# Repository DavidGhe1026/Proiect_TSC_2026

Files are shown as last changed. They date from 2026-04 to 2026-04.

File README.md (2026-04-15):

# InkTime Hardware Implementation

## Executive summary

This repository documents the **hardware implementation** of the InkTime device as captured in the provided schematic (MCU, power, sensors, haptics, USB, RF, and e‑paper interface circuitry). 

At a high level, the design uses an **nRF52840 SoC** as the main controller, powered from a **single‑cell Li‑ion/LiPo battery** through a **buck‑boost 3.3 V rail**, with **USB‑C input** feeding a **charger/power‑path PMIC**. The MCU communicates with the PMIC, regulator, IMU, fuel gauge, and haptic driver over a shared **I²C bus**, and drives the e‑paper connector using **SPI + GPIO** plus a dedicated **power‑gate and charge‑pump rail generator** for the panel high‑voltage rails. 

A conservative **standby (always‑on) current estimate** for the baseline configuration (MCU in System ON + RTC, regulator enabled, IMU in low‑power mode, fuel gauge in hibernate, haptic driver shut down, PMIC in battery-only mode) is **≈ 26.9 µA**, corresponding to **~155 days (100 mAh)** or **~310 days (200 mAh)** battery life (ignoring cell self‑discharge and assuming the e‑paper power domain is gated off while idle). 

## System block diagram and interconnects

```mermaid
flowchart LR
  USB["USB-C Receptacle"] -->|VBUS| PMIC["BQ25180 Charger + Power-Path"]
  USB -->|D+/D-| ESD["USBLC6-2SC6Y ESD"]
  ESD -->|USB FS| MCU["nRF52840"]

  PMIC -->|VBAT| BAT["1-cell Li-ion/LiPo"]
  BAT -->|VBAT| REG["RT6160A Buck-Boost -> 3V3"]
  REG -->|3V3| MCU

  MCU <-->|I2C| FG["MAX17048 Fuel Gauge"]
  MCU <-->|I2C| IMU["BMA421 Accelerometer"]
  MCU <-->|I2C| HAPT["DRV2605 Haptic Driver"]
  MCU -->|GPIO| BTN["Buttons: Up/Down/Enter"]

  MCU -->|SPI + GPIO| EPDIF["E-paper Connector"]
  MCU -->|PWR_EPD| EPDPOW["EPD Power Gate and Charge Pump"]

```

(Interconnects and blocks derived from the schematic.) 

### Electrical interface summary

The hardware uses four primary interconnect classes:

- **I²C (TWI)**: shared control/telemetry bus for PMIC, buck‑boost regulator, fuel gauge, IMU, and haptic driver.   
- **SPI (SPIM)**: e‑paper interface uses SCK/MOSI/CS plus dedicated GPIOs (DC, RST, BUSY).   
- **USB 2.0 Full Speed (Device)**: D+/D− plus VBUS detect, protected by low-capacitance ESD.   
- **RF single‑ended 2.4 GHz**: SoC ANT pin → matching network → chip antenna.   

Recommended bus configuration choices aligned with the component set:

- **I²C clock**: **400 kHz (Fast-mode)**. The nRF52840 TWI peripheral supports 100 kHz and 400 kHz operation, and DRV2605 explicitly specifies up to 400 kHz SCL without wait states.   
- **SPI mode**: nRF52840 SPIM supports SPI modes **0–3** (CPOL/CPHA configurable). Select the mode required by the e‑paper controller on the attached display/FPC.   
- **SPI frequency**: the nRF52840 supports high‑speed SPI up to **32 MHz** (subject to signal integrity and slave constraints).   

## Bill of materials

The table below lists **major ICs/modules and key electromechanical components**. Any item not clearly available as an in‑catalog JLC assembly part is marked **“JLC Global Sourcing / LCSC”** and should be sourced via that workflow (or substituted with a footprint‑compatible equivalent after verifying electrical limits and package). 

| Item | Designator(s) | MPN / Value | Qty | Purpose | Procurement (JLC preferred) | Datasheet (primary) |
|---|---|---:|---:|---|---|---|
| Main SoC | U1 | nRF52840 (aQFN73/QIAA family) | 1 | MCU + BLE radio + USB FS device | JLC Parts (C190794)  | nRF52840 Product Brief (currents/features); nRF52840 Product Specification (pin mapping, SPIM/TWI/USB details)  |
| Charger + power-path PMIC | IC? (PMIC block) | BQ25180YBGR | 1 | USB-powered Li‑ion charge management + SYS power-path + ship modes | JLC Global Sourcing / LCSC (search by MPN)  | BQ25180 datasheet |
| Buck‑boost 3.3 V regulator | IC? (reg block) | RT6160AWSC | 1 | VBAT → regulated 3V3 rail (I²C configurable) | JLC Global Sourcing / LCSC (search by MPN) | RT6160A datasheet |
| Buck‑boost inductor | L7 | 470 nH (FTC252012SR47MBCA) | 1 | Energy storage for RT6160A | JLC Parts (C5832368) | JLC/LCSC listing (includes datasheet link) |
| Fuel gauge | U3 | MAX17048G+T10 | 1 | Battery SOC/voltage reporting over I²C + alert | JLC Parts (C2682616) | MAX17048/MAX17049 datasheet |
| IMU (accelerometer) | U? (IMU block) | BMA421 | 1 | Motion sensing + interrupts (2x INT) | JLC Global Sourcing / LCSC (search by MPN) | BMA421 datasheet |
| Haptic driver | IC2 | DRV2605YZFR | 1 | Drives ERM/LRA actuator; I²C control | JLC Parts (C133542) | DRV2605 datasheet (I²C timing + currents) |
| USB ESD protection | D3 | USBLC6-2SC6Y (or footprint‑equivalent USBLC6-2SC6) | 1 | Protects D+/D− and VBUS; low line capacitance | JLC Parts (USBLC6‑2SC6, C7519) | USBLC6‑2SC6Y datasheet |
| USB‑C receptacle | J4 | KH‑TYPE‑C‑16P | 1 | USB‑C connection for VBUS and USB data | JLC Parts (C709357) | JLC part listing (datasheet link) |
| E‑paper FPC connector | J1 | 503480‑2400 (24‑pin) | 1 | E‑paper display interconnect | JLC Global Sourcing / LCSC (C2934918 listing) | LCSC listing (mechanical/datasheet link) |
| E‑paper power gate (P‑MOSFET) | Q1 | DMG2305UX‑7 | 1 | Switches EPD_3V3 power domain | JLC Parts (C425246) | JLC listing (datasheet link) |
| E‑paper analog switch / MOSFET | Q3 | SI1308EDL‑T1‑GE3 | 1 | Drives panel high‑voltage switching nodes (GDR/RESE path) | LCSC (C469327) | SI1308EDL datasheet |
| RF antenna | ANT1 | 2450AT18B100E (2.4 GHz chip antenna) | 1 | 2.4 GHz radiator | LCSC (C2917717) | Antenna datasheet (matching/layout guidance) |
| RF matching network | L/C near ANT/FEED | (e.g., 3.3 nH, 0.8 pF per reference values) | 1 set | Match SoC RF to antenna, tune return loss | JLC Parts (value/footprint‑based selection) | nRF52840 reference circuitry section (pin/usage context) |
| Buttons | SW_UP/SW_DN/SW_ENT | Tactile switches + resistors | 3 | User input | JLC Parts (value/footprint‑based selection) | N/A (component-series dependent) |

Notes:
- The schematic explicitly calls out **BQ25180YBGR**, **RT6160AWSC**, **MAX17048G+T10**, **DRV2605YZFR**, **USBLC6-2SC6Y**, **KH-TYPE-C-16P**, **503480-2400**, **DMG2305UX-7**, **SI1308EDL-T1-GE3**, and an **RF chip antenna** in the 2450AT18B100 family.  
- For USB ESD procurement, JLC lists **USBLC6‑2SC6**, while the schematic specifies **USBLC6‑2SC6Y**; they are footprint-compatible variants in the same family. Electrical limits must be checked for your exact variant.   

## Hardware functionality and implementation details

### Power path, charging, and system rails

**USB‑C input and protection.** The USB‑C receptacle provides VBUS and USB data lines; the design includes a dedicated ESD protection device protecting **D+/D− and VBUS** with very low capacitance to preserve signal integrity.  
The selected USBLC6 family is specified for **USB 2.0 ports up to 480 Mb/s** and lists typical **~2.5 pF** line capacitance and very low leakage (nA‑scale), which is appropriate for high‑speed data protection.

**Charger + power-path (BQ25180).** The PMIC provides a USB‑powered single‑cell charger with a regulated system rail (SYS) and multiple ultra‑low power modes. The datasheet indicates a **regulated SYS voltage range of 4.4–4.9 V** (configurable) and **ultra‑low quiescent current modes** including **~3 µA battery-only** and **~3.2 µA ship mode** (typical feature-level statements).  
This PMIC is controlled via **I²C** and can assert an **/INT** line to the MCU for events/faults (as reflected by the schematic net naming and the PMIC datasheet’s host interface concept).

**Battery rail (VBAT).** The battery node is distributed as **VBAT** and is also fed to the fuel gauge and to the buck‑boost converter input. The schematic provides test points for VBAT and ground for characterization.

**3.3 V rail generation (RT6160A buck‑boost).** VBAT is converted to a regulated **3V3** rail by RT6160A, a single‑inductor synchronous buck‑boost with an **I²C interface up to 1 MHz**, programmable VOUT range, and low quiescent current design (single‑digit µA typical, mode-dependent).  
The design uses a dedicated power inductor (470 nH class) consistent with the regulator’s application requirements. 

Operationally:
- At light loads, RT6160A uses automatic PFM/Deep Sleep to maintain efficiency and reduce quiescent loss.   
- The 3V3 rail powers the SoC and all low-voltage peripherals (IMU, fuel gauge, haptic driver logic).   

### Battery fuel gauge telemetry

The design uses **MAX17048** (ModelGauge) to estimate battery state‑of‑charge and voltage via **I²C**, and asserts an **ALRT** interrupt output for configurable thresholds.   
For always‑on operation, MAX17048 supports automatic entry into **hibernate mode (~3 µA)** while maintaining fuel gauging, and **active mode (~23 µA)** when needed.

### IMU (accelerometer) and wake signaling

The IMU is a **BMA421** 3‑axis accelerometer with **I²C/SPI digital interfaces** and **two interrupt pins**, allowing low‑power always‑on event detection without continuous MCU polling.   

Key current modes cited by the datasheet:
- Always-on/low-power operation down to **~13 µA (@ 50 Hz)**.  
- Step-counting “embedded intelligence” example at **~25 µA** (application-context value).  

The schematic routes **INT1** and **INT2** to two independent MCU GPIOs, enabling flexible wake/event mapping (e.g., wake-on-motion vs. tap).

### Haptic driver (DRV2605)

DRV2605 provides ERM/LRA drive with an internal library and closed-loop features, controlled over **I²C**.   
The I²C timing table specifies **fSCL up to 400 kHz** (no wait states), which aligns with using 400 kHz for the shared bus.   

Power management is implemented using the device **EN** pin:
- **Shutdown current** is specified in the **single‑digit µA** range (typ. 1.75 µA).   
This is consistent with an approach where the MCU asserts a dedicated **HAPTIC_EN** GPIO only when haptics are needed. 

### E‑paper connector, power gating, and charge‑pump rails

**Connector and signals.** The e‑paper interface is exposed on a 24‑pin FPC connector and includes:
- SPI signals (SCK, MOSI, CS) and control lines (DC, RST, BUSY).   
- Multiple panel electrode/drive pins labeled `EPD_Cx` (panel‑specific).   

**Dedicated e‑paper power domain (EPD_3V3).** The design includes a **load switch/power gate** using a P‑channel MOSFET (DMG2305UX‑7) controlled by a MCU GPIO (`PWR_EPD`). This enables aggressive power gating of the panel domain when not actively refreshing.   

**Charge pump / high-voltage rails.** The schematic shows a discrete inductor/diode/capacitor network generating labeled rails **PREVGH** and **PREVGL**, typical of e‑paper panel bias generation, using:
- Inductor **L5 = 68 µH**,  
- Multiple **MBR0530** Schottky diodes,  
- High‑voltage capacitors (e.g., 1 µF/50 V class).   
A dedicated MOSFET (SI1308EDL) participates in this drive/rail switching network.   

Because e‑paper panels/controllers vary widely, the exact timing, required rail voltages, and refresh energy depend on the specific display used; the board provides the foundational rails and switching nodes called out in the schematic.   

### USB device, VBUS detect, and ESD strategy

The nRF52840 QIAA package assigns dedicated pads for:
- **VBUS** (USB 5 V input for the on-chip USB regulator),  
- **D−** and **D+**,  
- **DECUSB** (USB 3.3 V regulator decoupling).   

The product specification notes that **VBUS and either VDDH or VDD are required for USB peripheral operation**, and VBUS transitions generate detection events (and can wake from System OFF).   

Externally, the USBLC6 device protects the USB lines while meeting USB 2.0 signal integrity constraints via low capacitance.   

### RF output, matching, and antenna

The nRF52840 provides a dedicated **ANT** RF pin (single-ended antenna connection).   
The schematic includes an RF feed/matching section and a 2.4 GHz chip antenna footprint.   

The selected antenna family (2450AT18B100E) is specified for the 2.4 GHz band (operational frequency range around **2400–2500 MHz** with 50 Ω impedance in the antenna datasheet family), and requires careful PCB layout and matching as guided by the antenna documentation.   

## nRF52840 pin mapping

This section provides an explicit mapping of **board signals → exact nRF52840 pins** and why those pins were selected. Pin naming and ball locations are taken from the nRF52840 QIAA pin assignment table.   
Net names are taken from the schematic. 

### Pin mapping table

| Subsystem | Net / signal | nRF52840 port pin | Package ball / pad | Dir. | Rationale / design notes |
|---|---|---|---|---|---|
| I²C bus | SDA | P0.06 | L1 | I/O | Shared I²C data line to PMIC/regulator/fuel gauge/IMU/haptic; placed on standard GPIO. |
| I²C bus | SCL | P0.07 | M2 | I/O | Shared I²C clock; nRF TWI supports 100/400 kHz; matches DRV2605 max 400 kHz. |
| Fuel gauge | ALERT | P0.09 (NFC1)* | L24 | In | Interrupt from MAX17048 ALRT; uses an available GPIO that is multiplexed with NFC1. |
| PMIC | PMIC_INT | P0.11 | T2 | In | Dedicated PMIC interrupt line; avoids NFC pins; keeps wake sources on port 0. |
| IMU | IMU_INT1 | P0.08 | N1 | In | Primary IMU interrupt line; BMA421 supports 2 interrupts. |
| IMU | IMU_INT2 | P1.08 | P2 | In | Secondary IMU interrupt (e.g., step vs. motion). |
| Haptics | HAPTIC_EN | P0.12 | U1 | Out | Gates DRV2605 EN for lowest-power shutdown when haptics unused. |
| Buttons | SW_UP | P0.13 | AD8 | In | User input GPIO; placed on port 0. |
| Buttons | SW_ENT | P0.14 | AC9 | In | User input GPIO; adjacent to SW_UP for simple routing. |
| Buttons | SW_DN | P1.02 | W24 | In | User input GPIO on port 1; preserves port 0 grouping for display control lines. |
| E‑paper SPI | SCK | P0.02 | A12 | Out | SPI clock; P0.02 is a standard GPIO/analog pin suitable for SPIM mapping. |
| E‑paper SPI | MOSI | P0.03 | B13 | Out | SPI MOSI; display write-only SPI is common; SPIM supports selectable pins. |
| E‑paper SPI | EPD_CS | P0.05 | K2 | Out | Chip select on a nearby GPIO; SPIM can map CSN to any GPIO if needed. |
| E‑paper GPIO | EPD_DC | P0.15 | AD10 | Out | Data/command select; grouped with other display GPIOs (RST/BUSY). |
| E‑paper GPIO | EPD_RST | P0.16 | AC11 | Out | Display reset; grouped with display signals. |
| E‑paper GPIO | EPD_BUSY | P0.17 | AD12 | In | Display busy/status; grouped with display signals. |
| E‑paper power | PWR_EPD | P1.01 | Y23 | Out | Enables the EPD_3V3 load switch to fully gate the high-draw e‑paper domain while idle. |
| USB | D− | D− | AD4 | I/O | Dedicated USB D− pin (USBD). |
| USB | D+ | D+ | AD6 | I/O | Dedicated USB D+ pin (USBD). |
| USB | VBUS detect / LDO input | VBUS | AD2 | In (power sense) | Required for USBD operation and VBUS detection events. |
| Debug | SWDIO | SWDIO | AC24 | I/O | SWD programming/debug. |
| Debug | SWDCLK | SWDCLK | AA24 | In | SWD clock. |
| Reset | nRESET | P0.18 / nRESET | AC13 | In | External reset capability configured on P0.18. |
| RF | ANT | ANT | H23 | RF | Single-ended antenna port → matching → antenna. |
| HF crystal | XC1 / XC2 | XC1 / XC2 | B24 / A23 | Analog | External 32 MHz crystal pins for the high-frequency clock reference. |
| LF crystal | XL1 / XL2 | P0.00 / P0.01 | D2 / F2 | Analog | 32.768 kHz crystal pins (low-frequency clock). |

\* **Note on NFC pins used as GPIO:** P0.09 and P0.10 are multiplexed with NFC1/NFC2 (NFCT antenna pins). Using P0.09 as a GPIO for ALERT implies the NFC function is not used (NFCT antenna would otherwise connect between NFC1 and NFC2).

## Power budget and battery-life estimates

This section provides a **standby baseline** and an example **active contributor** model. All currents below are **typical datasheet values** at nominal supply and assume the design is configured to use each component’s low‑power mode.

### Standby baseline current model

Assumed baseline state:
- nRF52840 in **System ON, full RAM retention + RTC** (wake on GPIO/RTC/interrupt).   
- RT6160A regulator enabled at light load (low quiescent current regime).   
- BQ25180 in **battery-only mode** (no adapter present).   
- MAX17048 in **hibernate**.  
- BMA421 in **low-power mode (~13 µA @ 50 Hz)**.  
- DRV2605 held in **shutdown via EN**.  
- E‑paper power domain gated off (PWR_EPD low).  

| Block | Typical current used | Source |
|---|---:|---|
| nRF52840 (System ON + RTC + full RAM retention) | 3.16 µA | nRF52840 product brief |
| RT6160A buck‑boost (light‑load quiescent) | 3 µA (typical feature statement) | RT6160A datasheet |
| BQ25180 (battery‑only mode) | 3 µA | BQ25180 datasheet |
| MAX17048 (hibernate) | 3 µA | MAX17048 datasheet |
| BMA421 (low‑power mode @ 50 Hz) | 13 µA | BMA421 datasheet |
| DRV2605 (shutdown) | 1.75 µA (typical) | DRV2605 datasheet |
| **Total baseline** | **≈ 26.9 µA** | Sum of the above |

### Standby current visualization (Mermaid bar chart)

```mermaid
xychart-beta
  title "Standby Current Contributors (Typical, µA)"
  x-axis ["nRF52840","RT6160A","BQ25180","MAX17048","BMA421","DRV2605"]
  y-axis "µA" 0 --> 30
  bar [3.16,3.0,3.0,3.0,13.0,1.75]
```

(Values used are taken from the cited datasheets/product brief above.) 

### Battery life examples (100 mAh and 200 mAh)

Battery life estimate uses:

<!-- \[
\text{Life (hours)} \approx \frac{C_{\text{mAh}}}{I_{\text{avg(mA)}}}
\quad\text{with}\quad
I_{\text{avg(mA)}} = \frac{I_{\text{avg(µA)}}}{1000}
\] -->

Baseline standby average current: **26.9 µA** (0.0269 mA). (Derived from the table above.) 

| Cell capacity | Avg current | Estimated life (hours) | Estimated life (days) |
|---:|---:|---:|---:|
| 100 mAh | 26.9 µA | ~3716 h | **~155 days** |
| 200 mAh | 26.9 µA | ~7432 h | **~310 days** |

These values **exclude**:
- cell self‑discharge,
- regulator efficiency variation with temperature/load,
- any periodic BLE, display refresh, or haptic events,
- leakage through external connectors/cabling.   

### Example “active contributor” model: BLE advertising overhead

The nRF52840 radio current is listed as **6.40 mA at 0 dBm TX** (DC/DC @ 3 V) and **6.26 mA in RX (1 Mbps)**.  

<!-- If the device performs periodic advertisements, the average current contribution is dominated by **TX/RX duty cycle**. A simple approximation:

\[
I_{\text{adv,avg}} \approx I_{\text{TX}} \cdot \frac{t_{\text{radio}}}{T_{\text{interval}}}
\] -->

<!-- **Worked example (assumption):** advertising interval **1 s**, total radio-on time **3 ms per interval** (3 channels + overhead).  
Then \( I_{\text{adv,avg}} \approx 6.4\text{ mA} \cdot 0.003 = 19.2\text{ µA} \). (TX current from datasheet; timing is a workload assumption.)   -->

New average: \( 26.9 + 19.2 \approx 46.1 \) µA.

| Cell capacity | Avg current | Estimated life (days) |
|---:|---:|---:|
| 100 mAh | ~46.1 µA | ~90 days |
| 200 mAh | ~46.1 µA | ~181 days |

## Assumptions and ambiguity list

1. **Exact nRF52840 orderable variant/package.** The schematic labels the SoC generically while the pinout corresponds to the **QIAA/aQFN73** variant (USB dedicated pins, SWD ball names). The BOM assumes the commonly stocked QIAA family part used by JLC (C190794) and uses the QIAA pin assignment table for ball names.   
2. **E‑paper panel/controller specifics are not provided.** The connector and discrete rail generation (PREVGH/PREVGL, GDR/RESE) are present, but **SPI mode, refresh timing, and refresh energy** depend on the attached panel/controller. The README treats these as panel‑dependent.   
3. **Procurement availability on JLC can change.** For components not explicitly found as a JLC in-catalog part in this research pass (e.g., BQ25180YBGR, RT6160AWSC, BMA421), procurement is marked **JLC Global Sourcing / LCSC search by MPN**, and an exact order flow should be validated before finalizing the assembly BOM.   
4. **USB ESD part number variant.** The schematic specifies USBLC6‑2SC6Y; JLC’s catalog listing used here is USBLC6‑2SC6 (same package family). Confirm the exact suffix requirements (automotive grade, qualification) for your build.   
5. **Power budget uses typical values and specific low-power modes.** Real current depends on firmware configuration (sleep state, RTC usage, GPIO pulls), regulator mode, and sensor configuration. The table is intended as an engineering starting point; measurement on the assembled board is required for sign-off.

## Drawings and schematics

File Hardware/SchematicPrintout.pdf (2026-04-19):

E-paper Drive Circuit | TP_OP

# TP_ON Haptic Driver

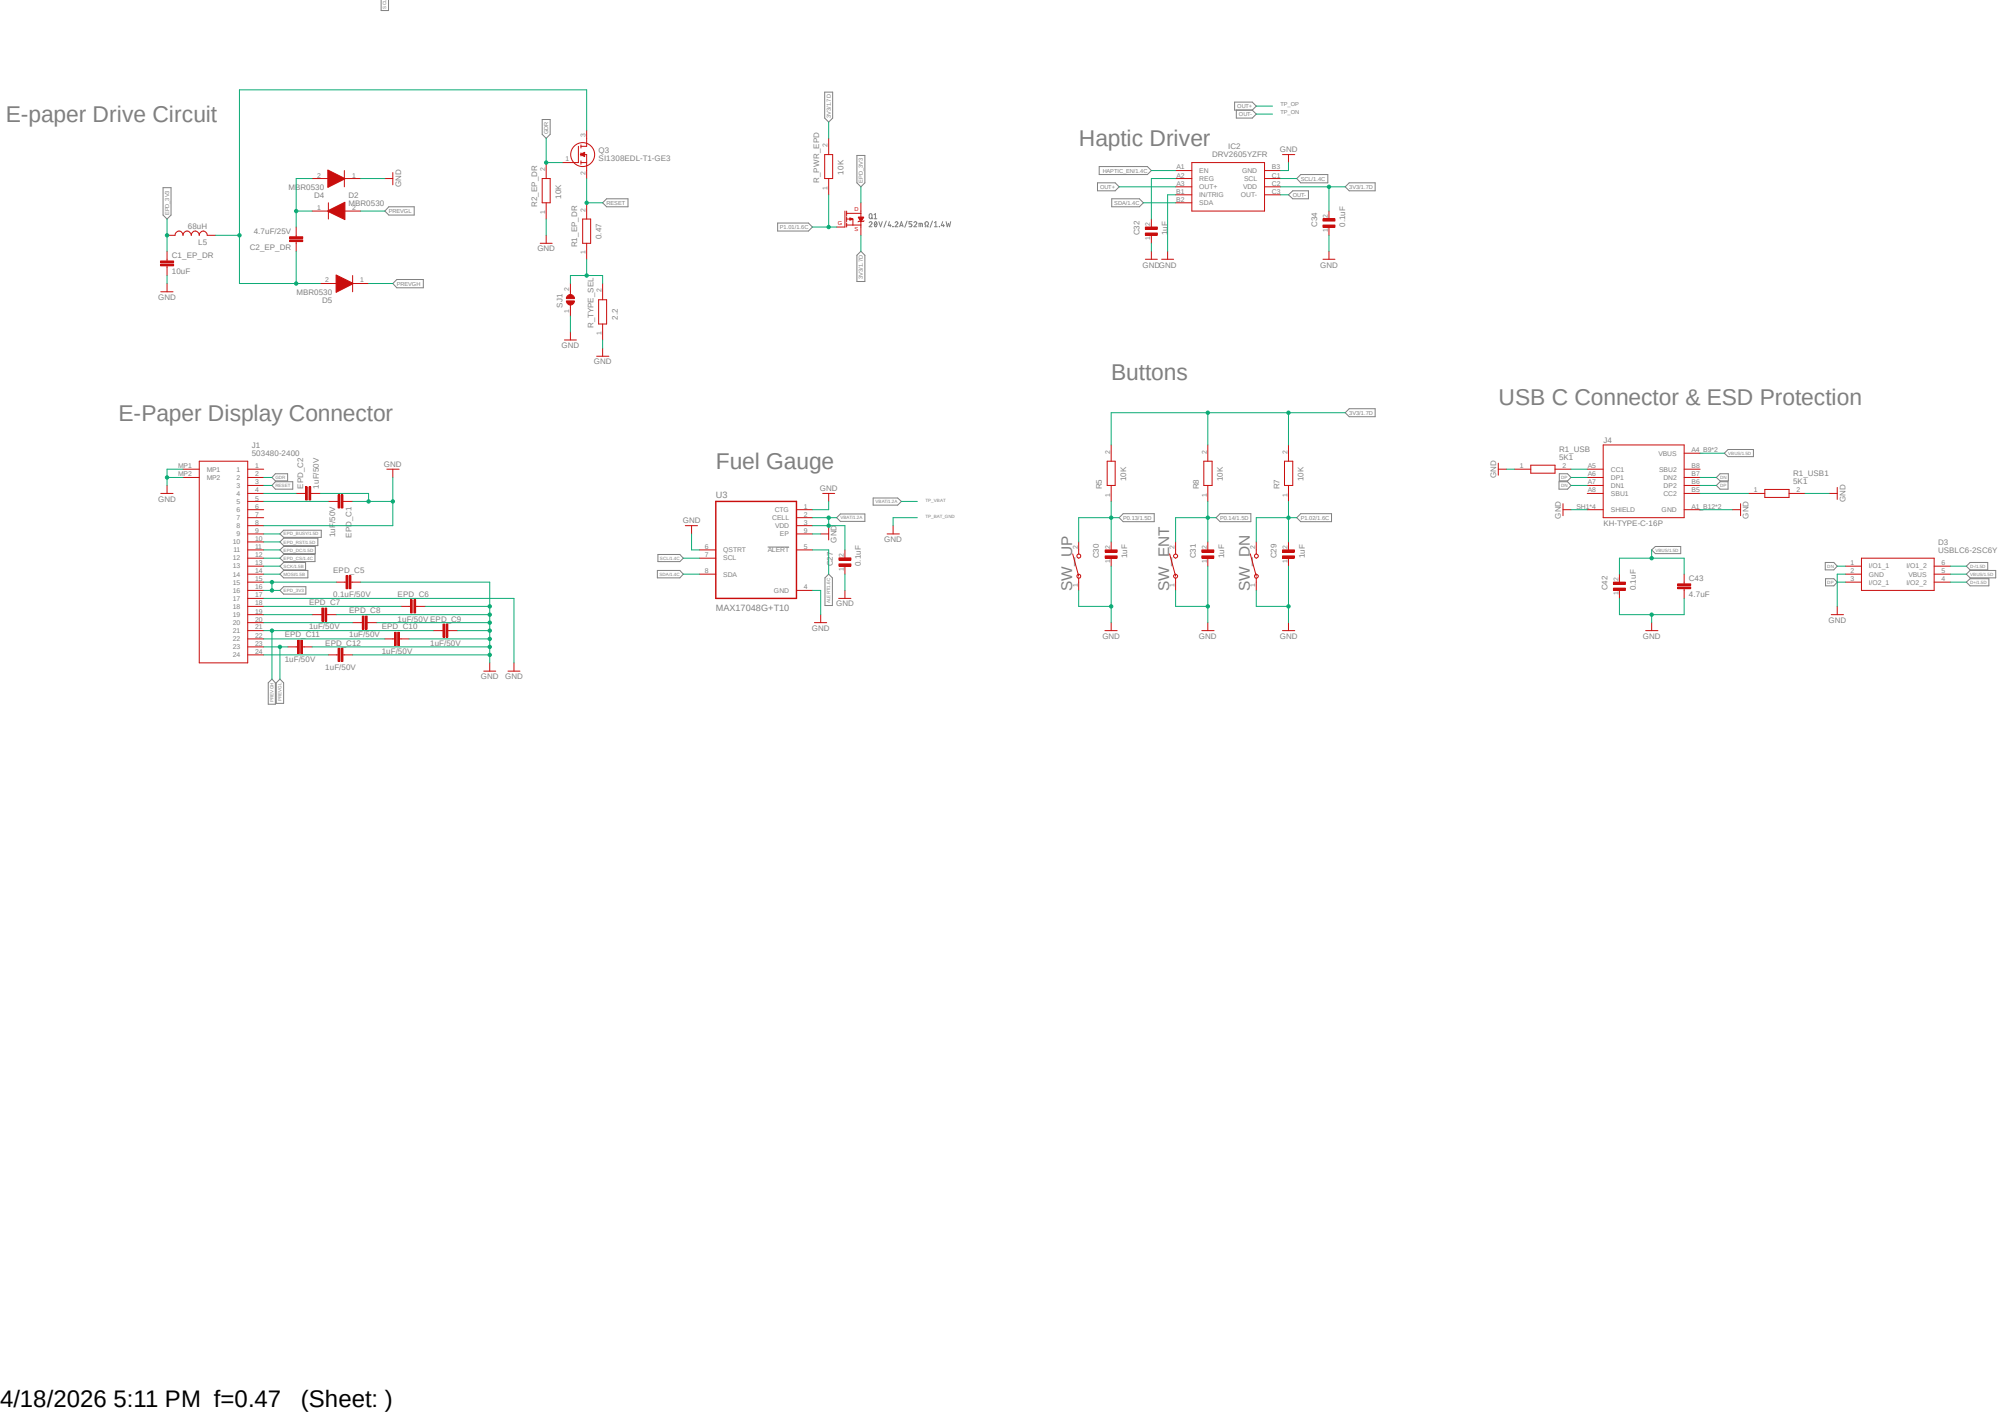
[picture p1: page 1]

USB C Connector & ESD Protection

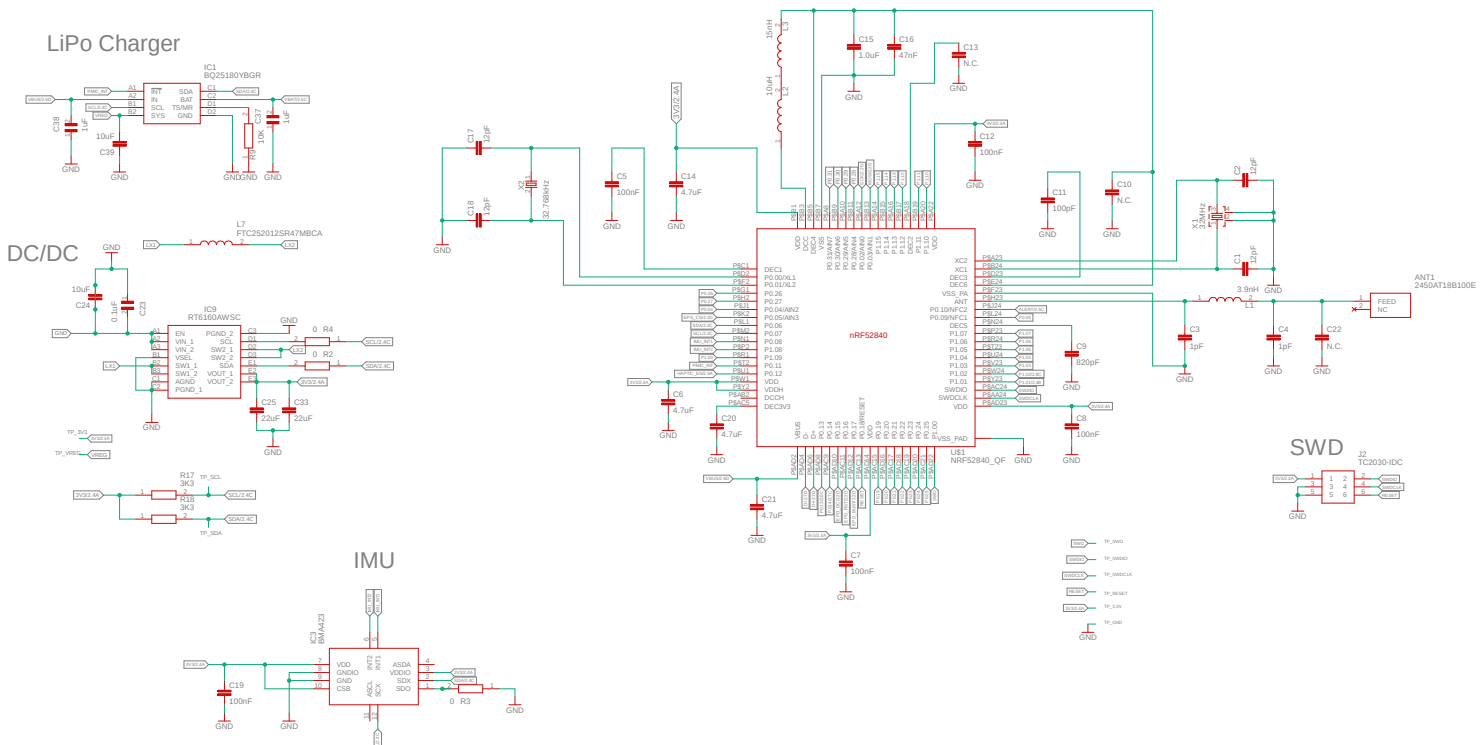
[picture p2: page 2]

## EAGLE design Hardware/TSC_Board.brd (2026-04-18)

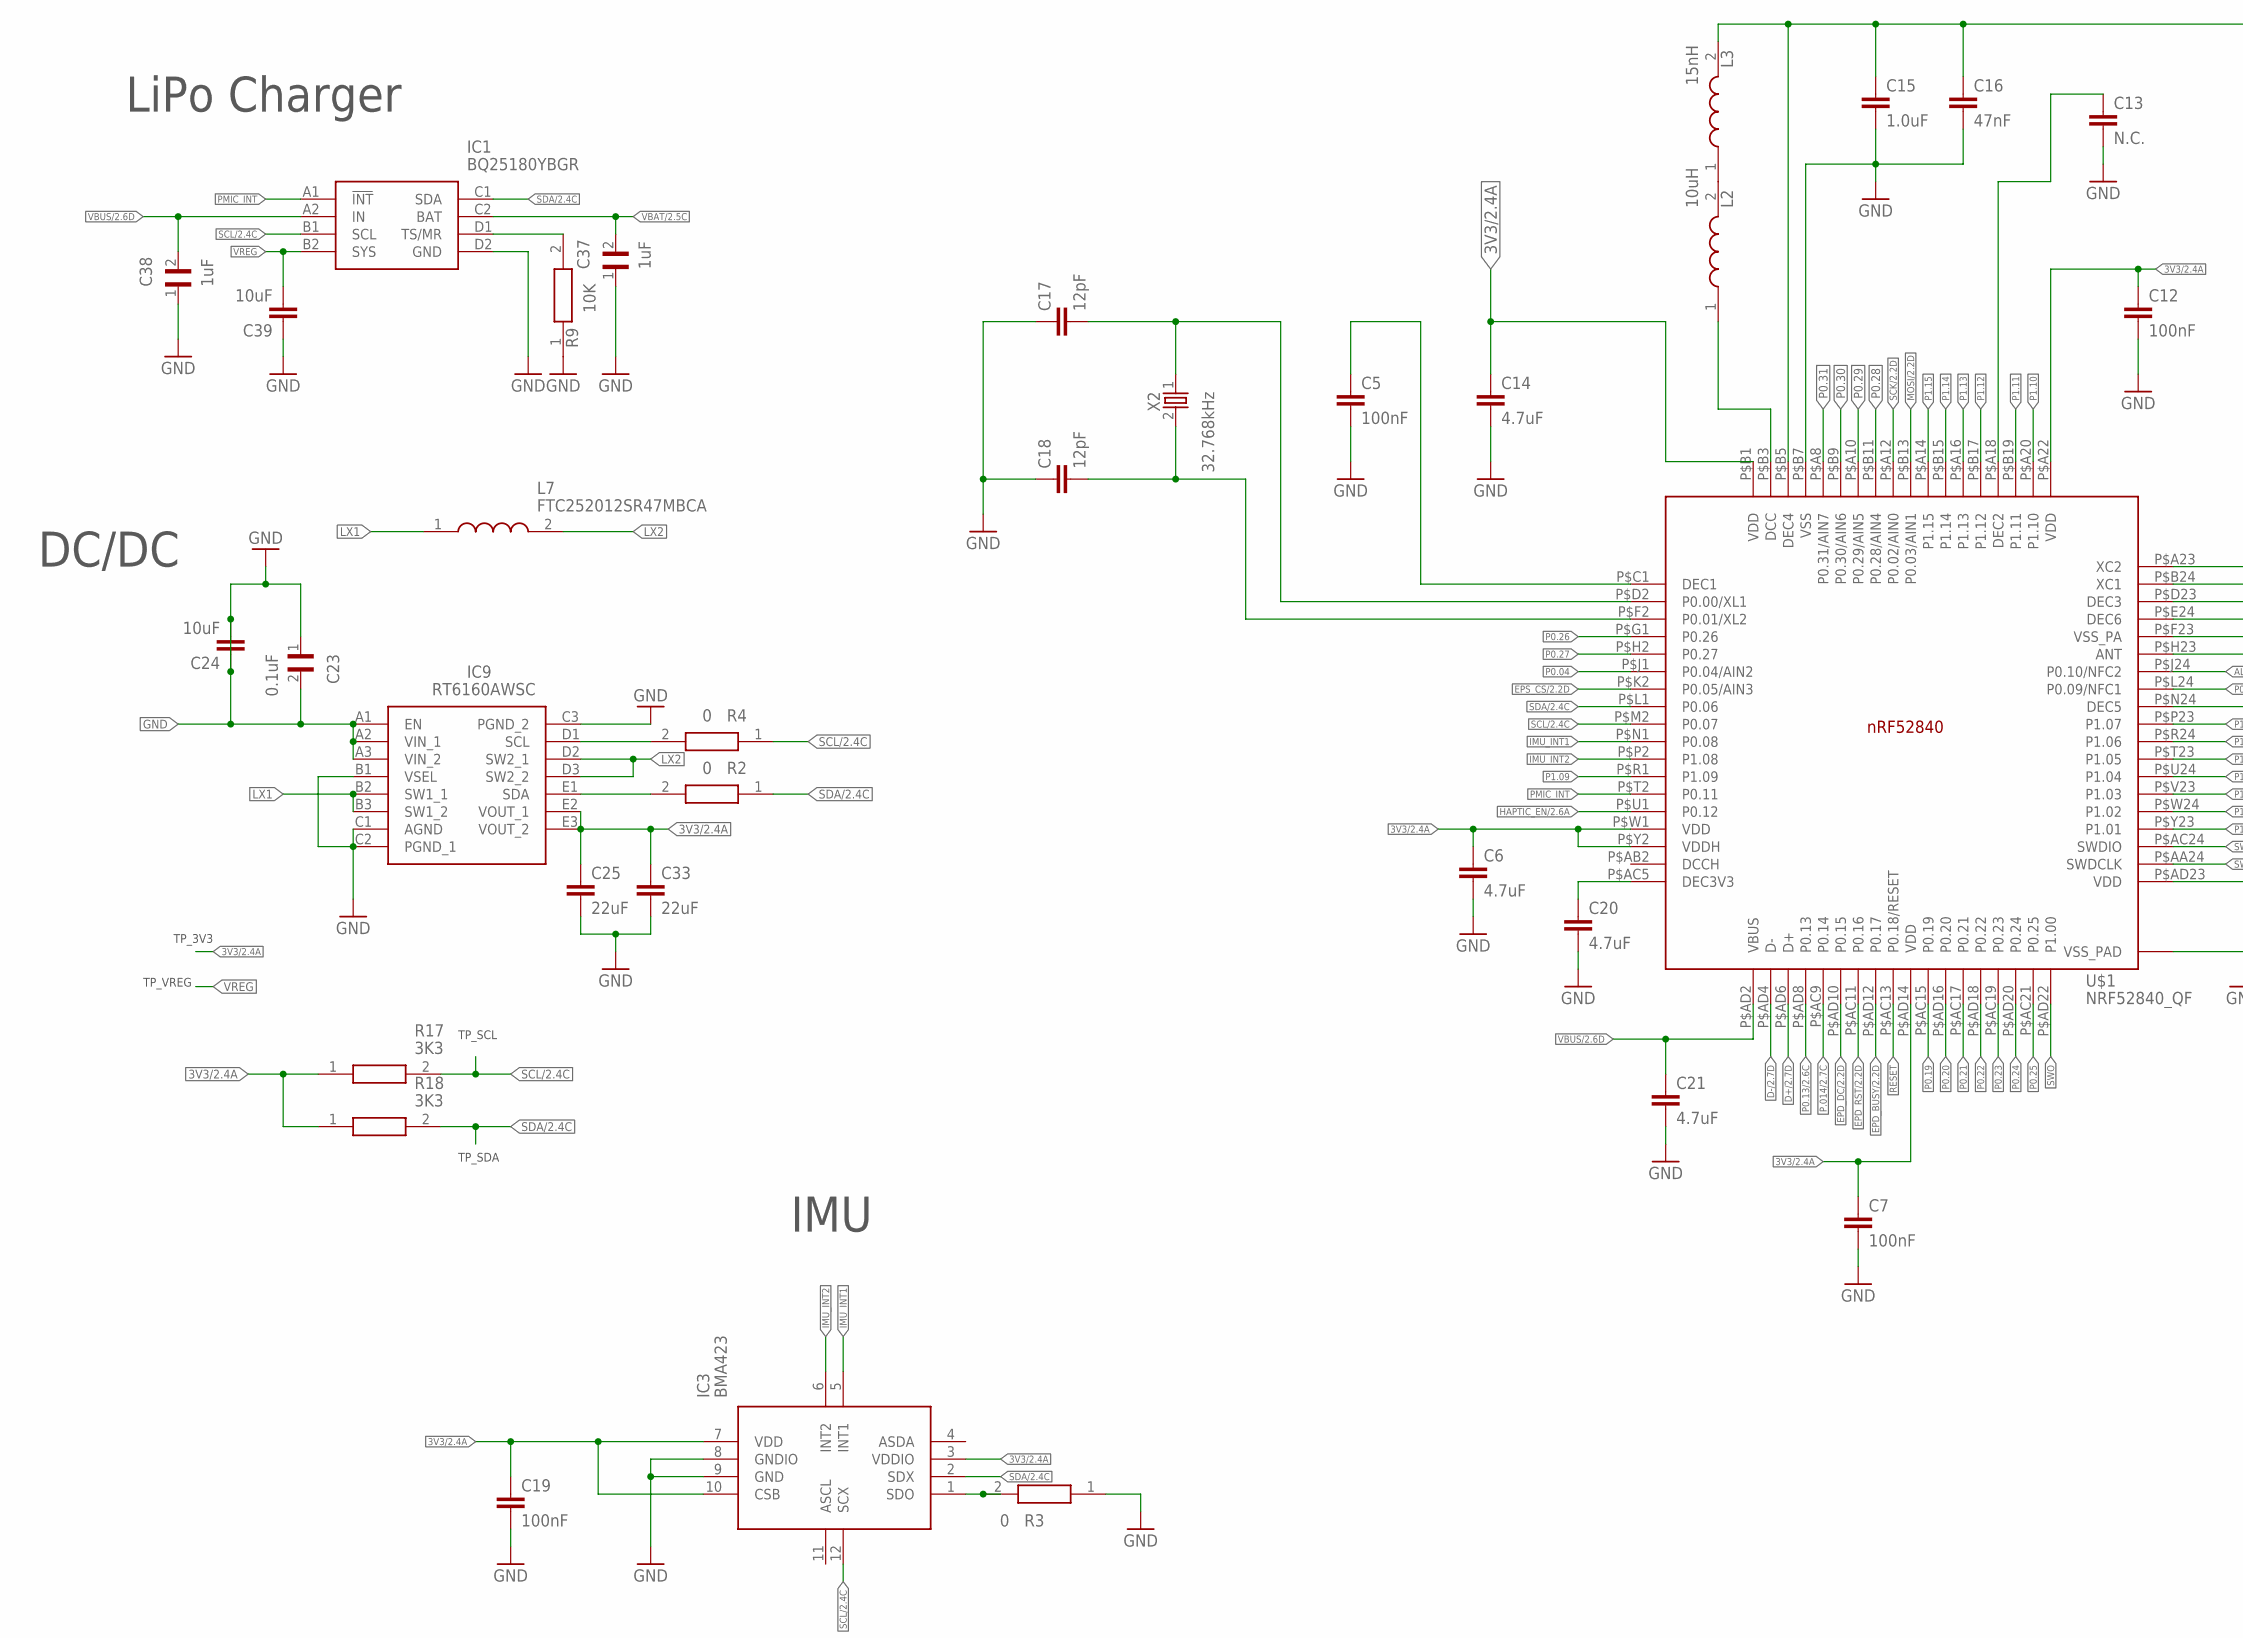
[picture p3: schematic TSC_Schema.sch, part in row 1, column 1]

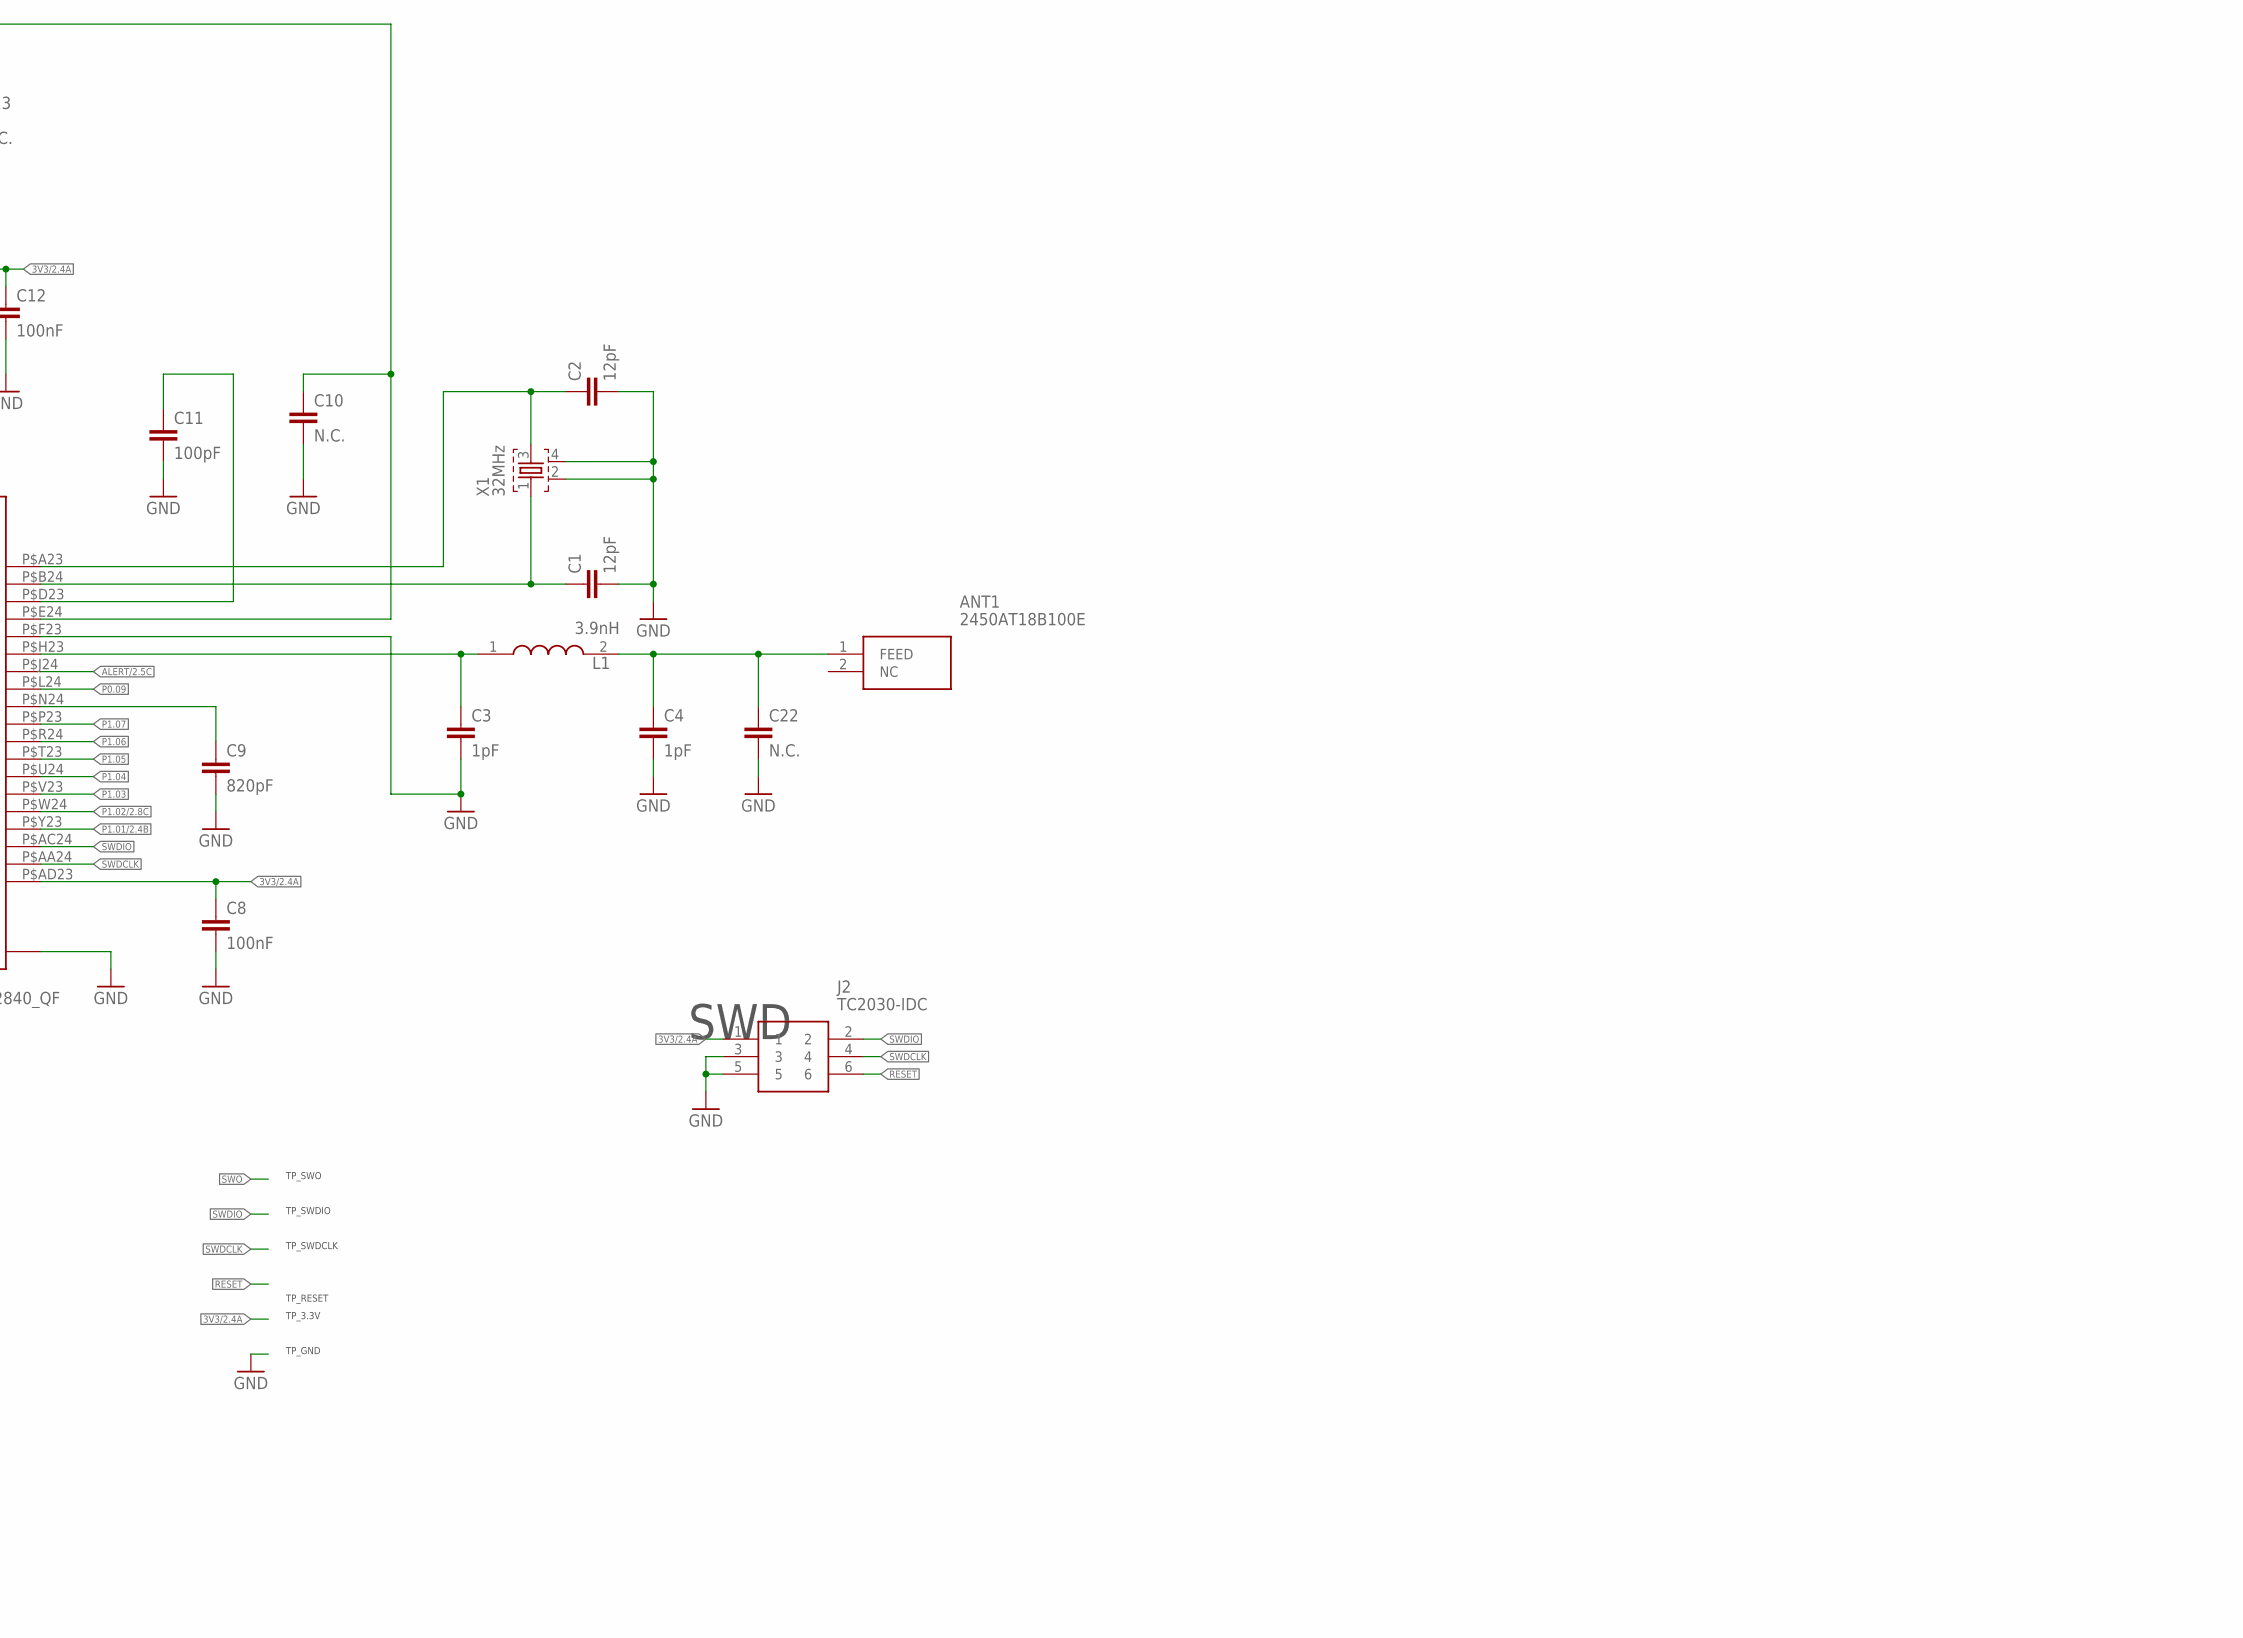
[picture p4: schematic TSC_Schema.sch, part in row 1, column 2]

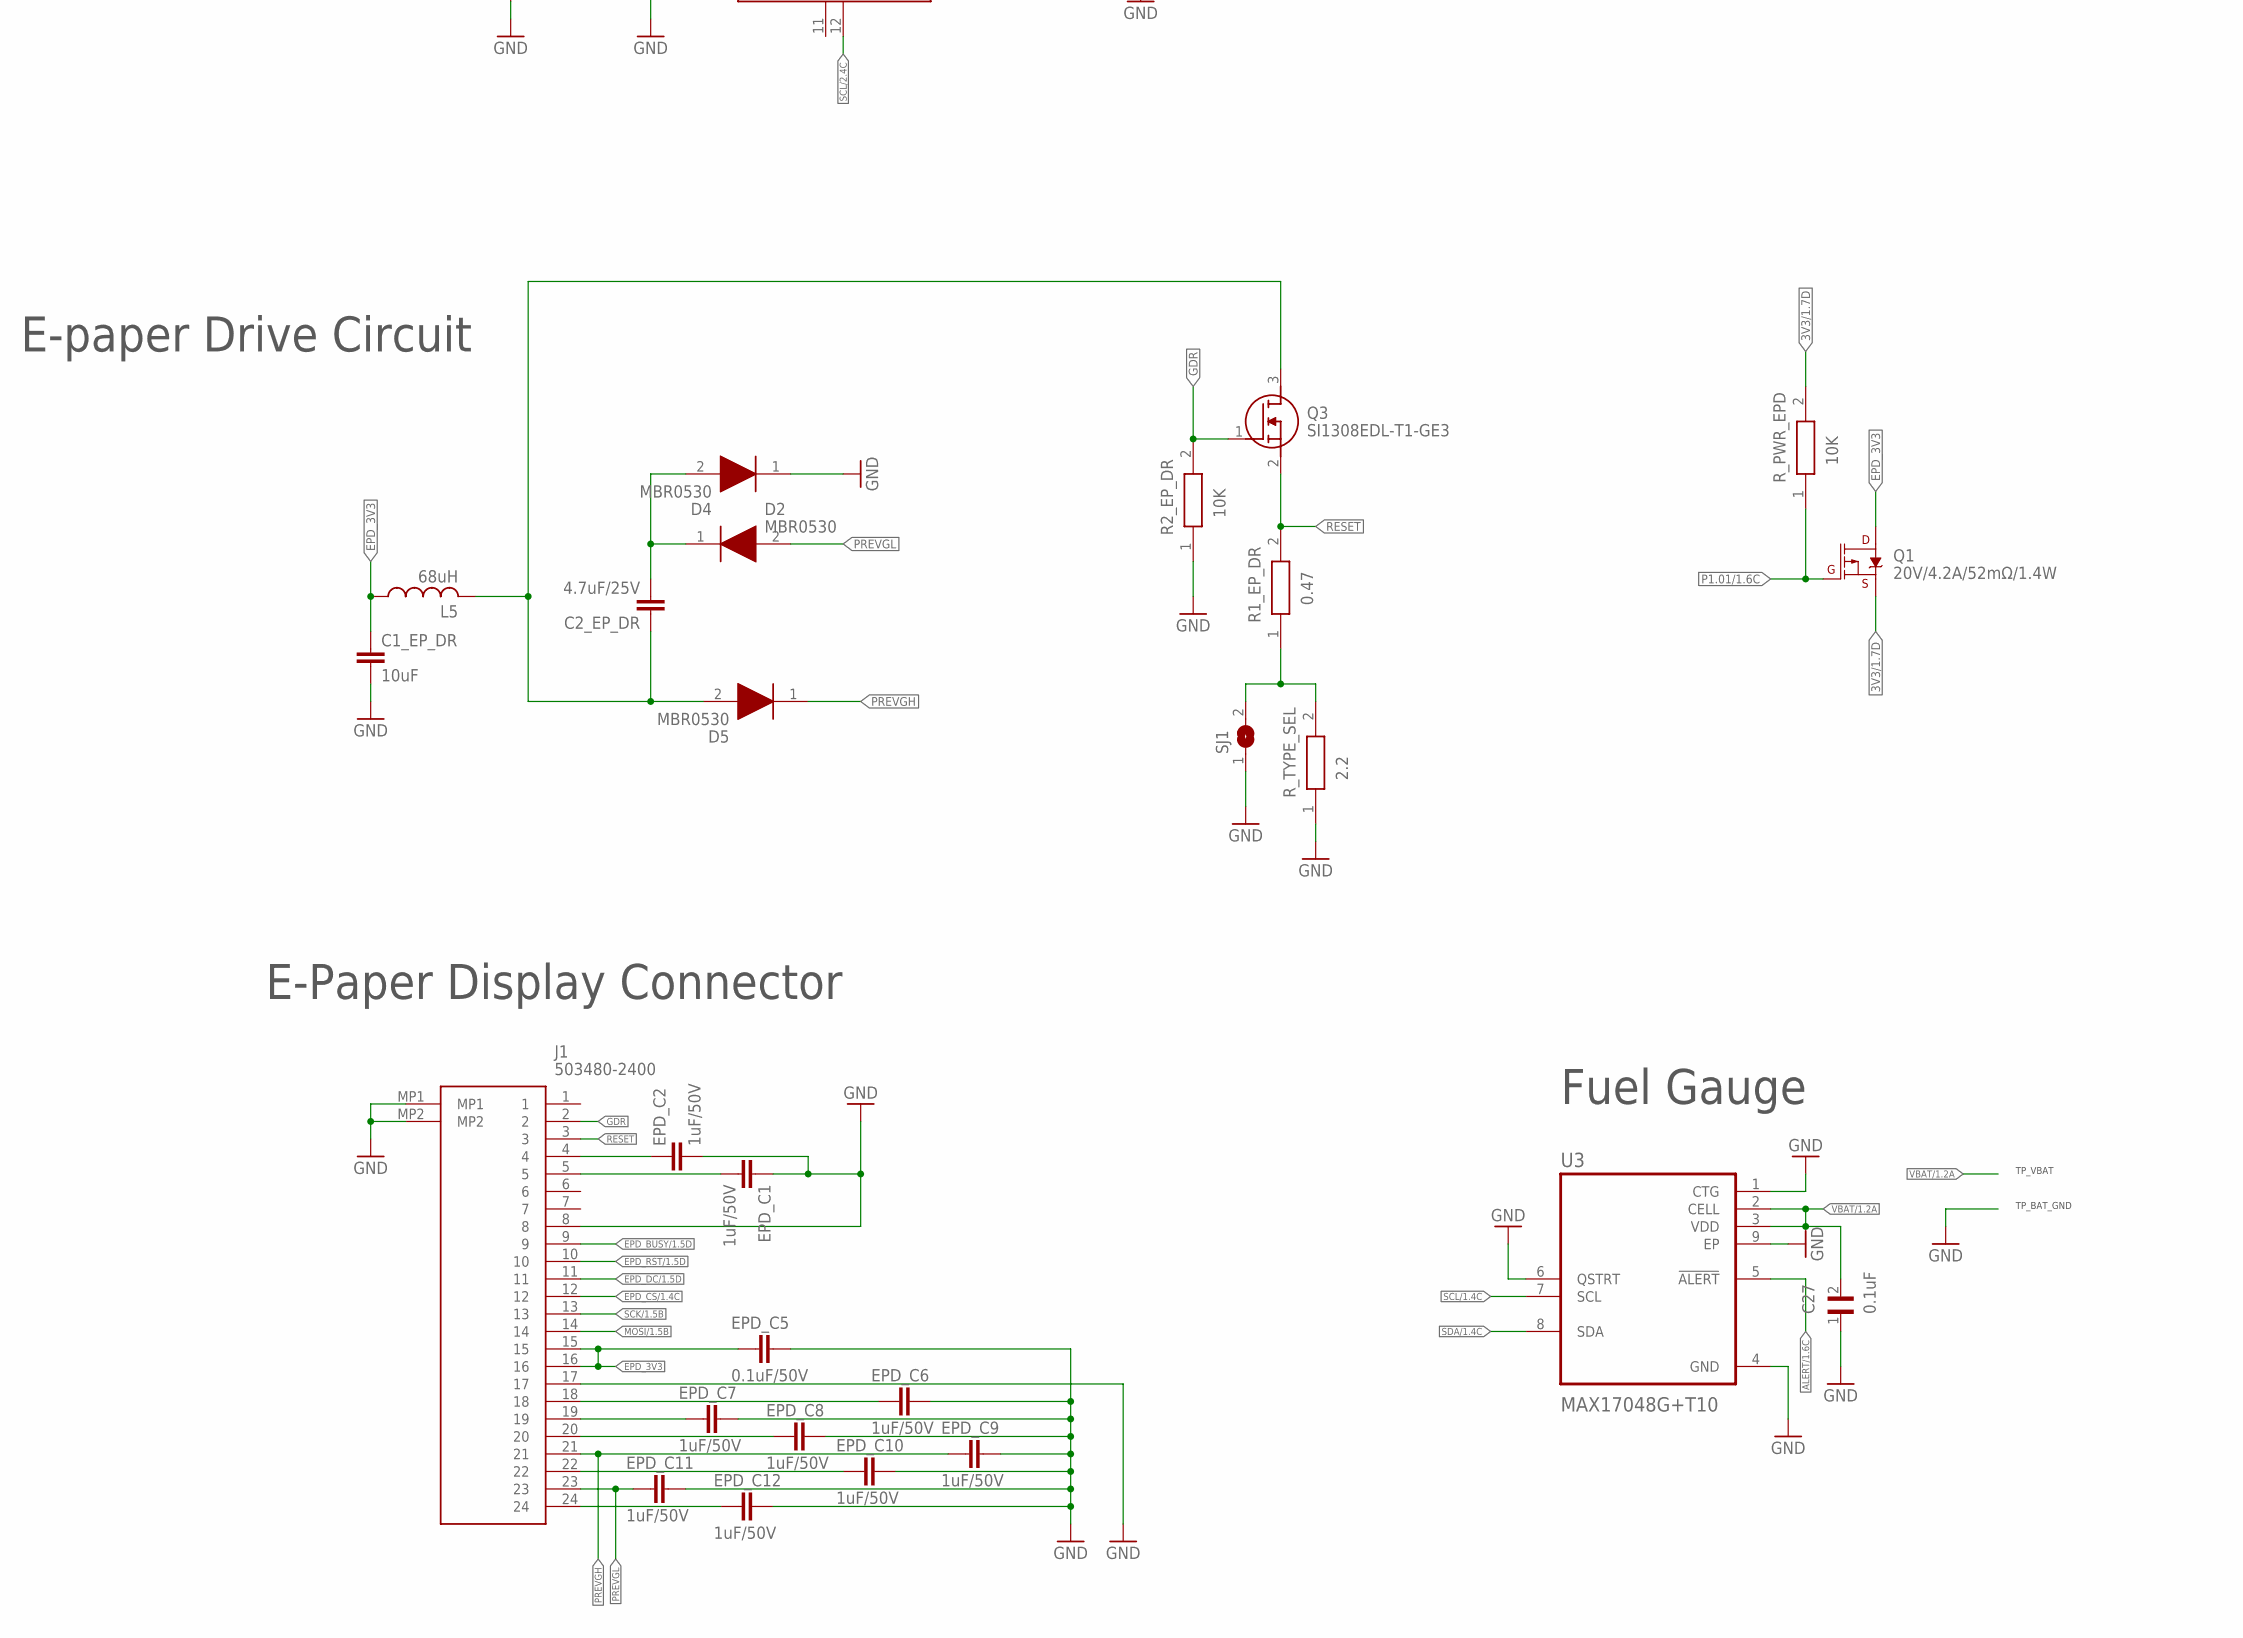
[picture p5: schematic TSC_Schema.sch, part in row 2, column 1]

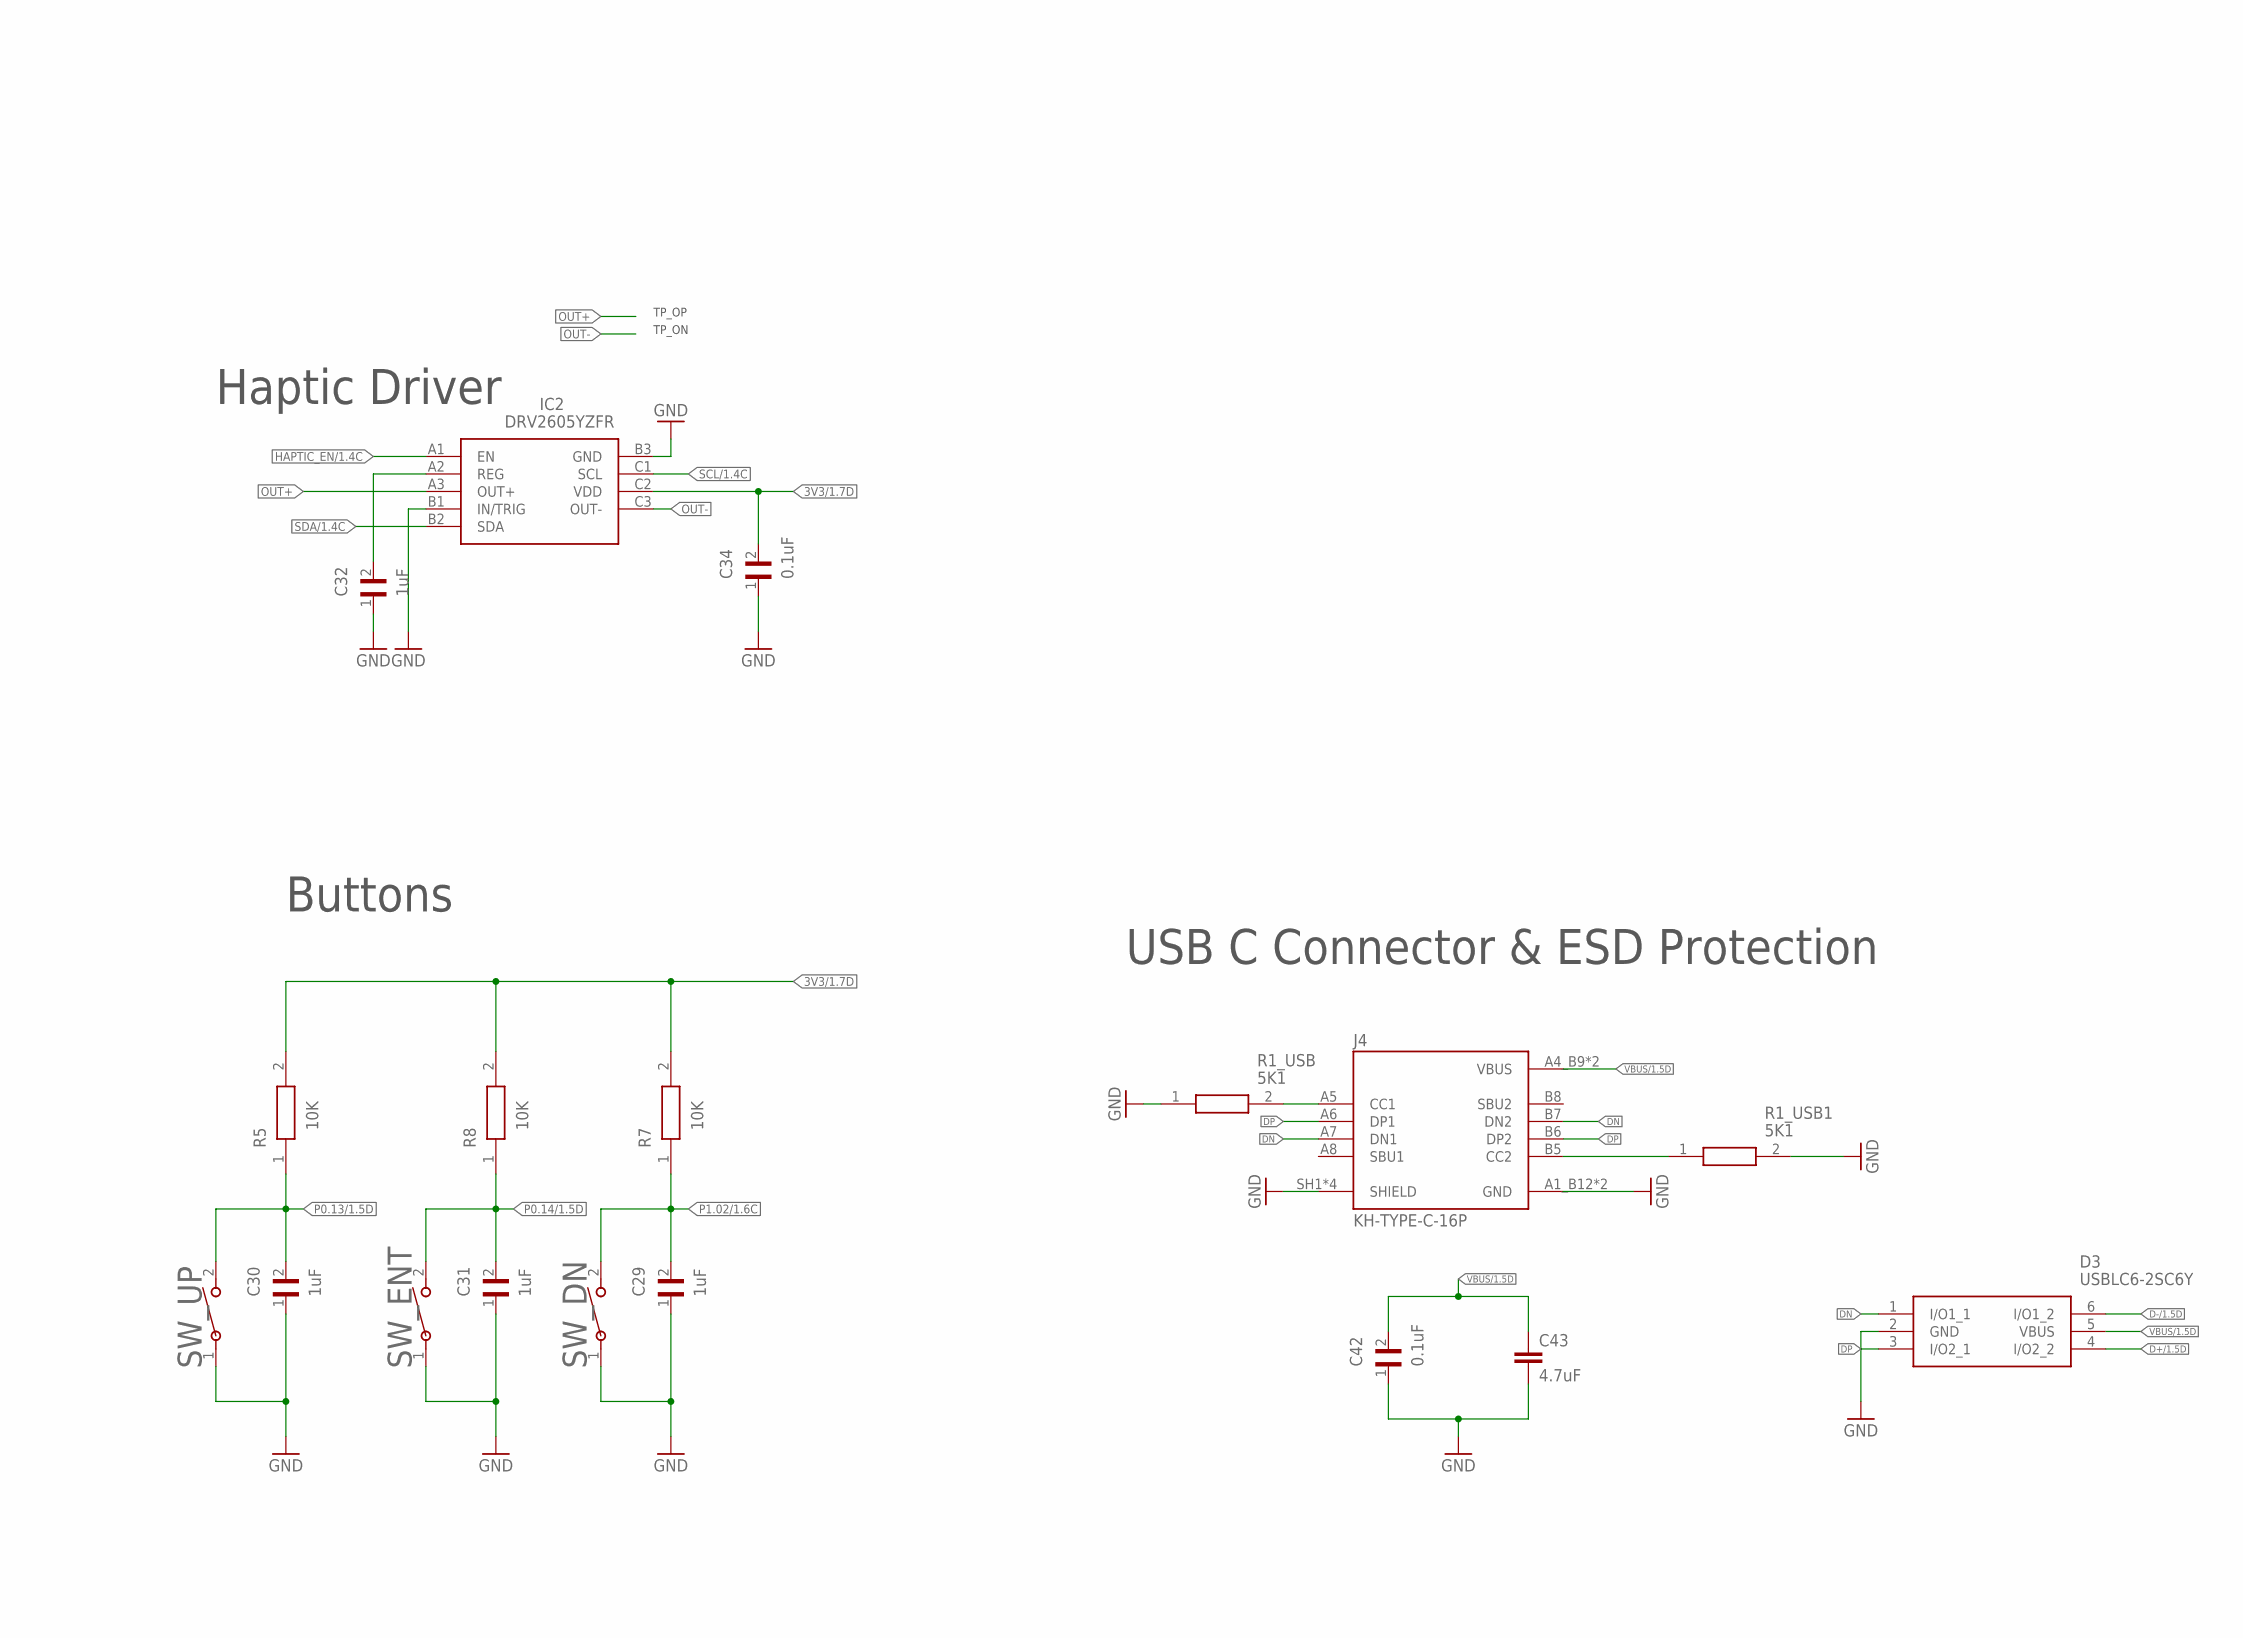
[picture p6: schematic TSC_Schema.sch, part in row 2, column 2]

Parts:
ANT1: 2450AT18B100E; 2450AT18B100E_ANTC3216X140N
C1, C2, C17, C18: 12pF; NORDIC_NRF_3_RESC0402_N
C1_EP_DR, C24, C39: 10uF; NORDIC_NRF_3_RESC0402_N
C2_EP_DR: 4.7uF/25V; NORDIC_NRF_3_RESC0402_N
C3, C4: 1pF; NORDIC_NRF_3_RESC0402_N
C5, C7, C8, C12, C19: 100nF; NORDIC_NRF_3_RESC0402_N
C6, C14, C20, C21, C43: 4.7uF; NORDIC_NRF_3_RESC0402_N
C9: 820pF; NORDIC_NRF_3_RESC0402_N
C10, C13, C22: N.C.; NORDIC_NRF_3_RESC0402_N
C11: 100pF; NORDIC_NRF_3_RESC0402_N
C15: 1.0uF; ESP32_C6_LIBRARY_1_ESP32_WROVER_EAGLE-LTSPICE_C0402
C16: 47nF; ESP32_C6_LIBRARY_1_ESP32_WROVER_EAGLE-LTSPICE_C0402
C23, C27, C34, C42: 0.1uF; GRM011R60J152KE01L_2_CAPC0201X13N
C25, C33: 22uF; NORDIC_NRF_3_RESC0402_N
C29, C30, C31, C32, C37, C38: 1uF; GRM011R60J152KE01L_2_CAPC0201X13N
D2, D4, D5: MBR0530; ESP32_C6_LIBRARY_5_SOD3716X135N
D3: USBLC6-2SC6Y; ESP32_C6_LIBRARY_3_SOT95P280X145-6N
EPD_C1, EPD_C2, EPD_C6, EPD_C7, EPD_C8, EPD_C9, EPD_C10, EPD_C11, EPD_C12: 1uF/50V; NORDIC_NRF_3_RESC0402_N
EPD_C5: 0.1uF/50V; NORDIC_NRF_3_RESC0402_N
IC1: BQ25180YBGR; BQ25180YBGR_BGA8C40P2X4_100X155X50
IC2: DRV2605YZFR; DRV2605YZFR_BGA9C50P3X3_144X144X62
IC3: BMA423; BMA423_BMA423
IC9: RT6160AWSC; RT6160AWSC_BGA15C40P3X5_140X230X60
J1: 503480-2400; 503480-2400_5034802400
J2: TC2030-IDC; TC2030-IDC_TC2030IDC
J4: KH-TYPE-C-16P; KH-TYPE-C-16P_KINGHELM_KH-TYPE-C-16P
L1: 3.9nH; MLP2016SR47MT0S1_INDC2016X100N
L2: 10uH; MLP2016SR47MT0S1_INDC2016X100N
L3: 15nH; MLP2016SR47MT0S1_INDC2016X100N
L5: 68uH; NORDIC_NRF_2_RESC0402_L
L7: FTC252012SR47MBCA; MLP2016SR47MT0S1_INDC2016X100N
Q1: 20V/4.2A/52mΩ/1.4W; ESP32_C6_LIBRARY_4_ESP32_C6_LIBRARY_4_ESP32_C6_LIBRARY_4_ES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
Q3: SI1308EDL-T1-GE3; ESP32_C6_LIBRARY_6_SOT65P210X110-3N
R1_EP_DR: 0.47; CPF0201D7K68C1_0201
R1_USB, R1_USB1: 5K1; CPF0201D7K68C1_0201
R2, R3, R4: 0; CPF0201D7K68C1_0201
R2_EP_DR, R5, R7, R8, R9: 10K; CPF0201D7K68C1_0201
R17, R18: 3K3; CPF0201D7K68C1_0201
R_PWR_EPD: 10K; CPF0201D7K68C1_0201
R_TYPE_SEL: 2.2; CPF0201D7K68C1_0201
SJ1: ESP32_C6_LIBRARY_7_JUMPER_SJ
SW_DN: 2025-10-22_07-23-44_LIBRARY_EVP-AKE31ASW_EVP-AKE3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; 2025-10-22_07-23-44_LIBRARY_SW_EVP-AKE31A_PAN
SW_ENT: 2025-10-22_07-23-44_LIBRARY_EVP-AKE31ASW_EVP-AKE3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; 2025-10-22_07-23-44_LIBRARY_SW_EVP-AKE31A_PAN
SW_UP: 2025-10-22_07-23-44_LIBRARY_EVP-AKE31ASW_EVP-AKE3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; 2025-10-22_07-23-44_LIBRARY_SW_EVP-AKE31A_PAN
U3: MAX17048G+T10; ESP32_C6_LIBRARY_SON50P200X200X80-9N
U$1: NRF52840_QF; NORDIC_NRF_4_AQFN50P700X700X85_HS-74N
X1: 32MHz; NORDIC_NRF_BT-XTAL_2016_N
X2: 32.768kHz; NORDIC_NRF_1_XTAL_3215_N

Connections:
3V3/1.7D: C34.2, IC2.C2 (VDD), Q1.2 (S), R5.2, R7.2, R8.2, R_PWR_EPD.2
3V3/2.4A: C6.1, C7.1, C8.1, C12.1, C14.1, C19.1, C25.1, C33.1, IC3.3 (VDDIO), IC3.7 (VDD), IC3.10 (CSB), IC9.E2 (VOUT_1), IC9.E3 (VOUT_2), J2.1, R17.1, R18.1, U$1.P$A22 (VDD), U$1.P$AD14 (VDD), U$1.P$AD23 (VDD), U$1.P$B1 (VDD), U$1.P$W1 (VDD), U$1.P$Y2 (VDDH)
ALERT/1.6C: U3.5 (!ALERT)
ALERT/2.5C: U$1.P$J24 (P0.10/NFC2)
D+/1.5D: D3.4 (I/O2_2)
D+/2.7D: U$1.P$AD6 (D+)
D-/1.5D: D3.6 (I/O1_2)
D-/2.7D: U$1.P$AD4 (D-)
DEC3: C11.1, U$1.P$D23 (DEC3)
DEC4_6: C10.1, C15.1, C16.1, L3.2, U$1.P$B5 (DEC4), U$1.P$E24 (DEC6)
DN: D3.1 (I/O1_1), J4.A7 (DN1), J4.B7 (DN2)
DP: D3.3 (I/O2_1), J4.A6 (DP1), J4.B6 (DP2)
EPD_3V3: C1_EP_DR.1, EPD_C5.2, J1.15, J1.16, L5.1, Q1.3 (D)
EPD_BUSY/1.5D: J1.9
EPD_BUSY/2.2D: U$1.P$AD12 (P0.17)
EPD_CS/1.4C: J1.12
EPD_DC/1.5D: J1.11
EPD_DC/2.2D: U$1.P$AD10 (P0.15)
EPD_RST/1.5D: J1.10
EPD_RST/2.2D: U$1.P$AC11 (P0.16)
EPS_CS/2.2D: U$1.P$K2 (P0.05/AIN3)
GDR: J1.2, Q3.1 (G), R2_EP_DR.2
GND: C1.2, C1_EP_DR.2, C2.2, C3.2, C4.2, C5.2, C6.2, C7.2, C8.2, C9.2, C10.2, C11.2, C12.2, C13.2, C14.2, C15.2, C16.2, C17.1, C18.1, C19.2, C20.2, C21.2, C22.2, C23.1, C23.2, C24.1, C24.2, C25.2, C27.1, C29.1, C30.1, C31.1, C32.1, C33.2, C34.1, C37.1, C38.1, C39.1, C42.1, C43.2, D3.2 (GND), D4.1 (K), EPD_C1.1, EPD_C2.2, EPD_C5.1, EPD_C6.1, EPD_C7.1, EPD_C8.1, EPD_C9.1, EPD_C10.1, EPD_C11.1, EPD_C12.1, IC1.D2 (GND), IC2.B1 (IN/TRIG), IC2.B3 (GND), IC3.8 (GNDIO), IC3.9 (GND), IC9.A1 (EN), IC9.A2 (VIN_1), IC9.A3 (VIN_2), IC9.B1 (VSEL), IC9.C1 (AGND), IC9.C2 (PGND_1), IC9.C3 (PGND_2), J1.8, J1.17, J1.MP1, J1.MP2, J2.3, J2.5, J4.A1_B12 (GND), J4.A12_B1 (GND), J4.SH1 (SHIELD), J4.SH2 (SHIELD), J4.SH3 (SHIELD), J4.SH4 (SHIELD), R1_USB.1, R1_USB1.2, R2_EP_DR.1, R3.1, R9.1, R_TYPE_SEL.1, SJ1.1, SW_DN.1, SW_ENT.1, SW_UP.1, U3.1 (CTG), U3.4 (GND), U3.6 (QSTRT), U3.9 (EP), U$1.P$74 (VSS_PAD), U$1.P$75 (VSS_PAD), U$1.P$76 (VSS_PAD), U$1.P$77 (VSS_PAD), U$1.P$78 (VSS_PAD), U$1.P$79 (VSS_PAD), U$1.P$80 (VSS_PAD), U$1.P$81 (VSS_PAD), U$1.P$82 (VSS_PAD), U$1.P$83 (VSS_PAD), U$1.P$84 (VSS_PAD), U$1.P$85 (VSS_PAD), U$1.P$86 (VSS_PAD), U$1.P$87 (VSS_PAD), U$1.P$88 (VSS_PAD), U$1.P$89 (VSS_PAD), U$1.P$90 (VSS_PAD), U$1.P$B7 (VSS), U$1.P$F23 (VSS_PA), X1.2, X1.4
HAPTIC_EN/1.4C: IC2.A1 (EN)
HAPTIC_EN/2.6A: U$1.P$U1 (P0.12)
IMU_INT1: IC3.5 (INT1), U$1.P$N1 (P0.08)
IMU_INT2: IC3.6 (INT2), U$1.P$P2 (P1.08)
LX1: IC9.B2 (SW1_1), IC9.B3 (SW1_2), L7.1
LX2: IC9.D2 (SW2_1), IC9.D3 (SW2_2), L7.2
MOSI/1.5B: J1.14
MOSI/2.2D: U$1.P$B13 (P0.03/AIN1)
unnamed: L2.1, U$1.P$B3 (DCC)
unnamed: L2.2, L3.1
unnamed: C13.1, U$1.P$A18 (DEC2)
unnamed: C1.1, U$1.P$B24 (XC1), X1.1
unnamed: C2.1, U$1.P$A23 (XC2), X1.3
unnamed: ANT1.1 (FEED), C4.1, C22.1, L1.2
unnamed: C3.1, L1.1, U$1.P$H23 (ANT)
unnamed: C9.1, U$1.P$N24 (DEC5)
unnamed: C5.1, U$1.P$C1 (DEC1)
unnamed: C17.2, U$1.P$D2 (P0.00/XL1), X2.1
unnamed: C18.2, U$1.P$F2 (P0.01/XL2), X2.2
unnamed: C20.1, U$1.P$AC5 (DEC3V3)
unnamed: IC3.1 (SDO), R3.2
unnamed: IC9.D1 (SCL), R4.2
unnamed: IC9.E1 (SDA), R2.2
unnamed: IC1.D1 (TS/MR), R9.2
unnamed: C2_EP_DR.1, D5.2 (A), L5.2, Q3.3 (D)
unnamed: R1_EP_DR.1, R_TYPE_SEL.2, SJ1.2
unnamed: C2_EP_DR.2, D2.1 (K), D4.2 (A)
unnamed: C32.2, IC2.A2 (REG)
unnamed: EPD_C2.1, J1.4
unnamed: EPD_C1.2, J1.5
unnamed: EPD_C7.2, J1.19
unnamed: EPD_C6.2, J1.18
unnamed: EPD_C8.2, J1.20
unnamed: C29.2, R7.1, SW_DN.2
unnamed: EPD_C10.2, J1.22
unnamed: J4.A5 (CC1), R1_USB.2
unnamed: EPD_C12.2, J1.24
unnamed: J4.B5 (CC2), R1_USB1.1
OUT+: IC2.A3 (OUT+)
OUT-: IC2.C3 (OUT-)
P0.1: U$1.P$A10 (P0.29/AIN5)
P0.2: U$1.P$B11 (P0.28/AIN4)
P0.04: U$1.P$J1 (P0.04/AIN2)
P0.09: U$1.P$L24 (P0.09/NFC1)
P0.13/1.5D: C30.2, R5.1, SW_UP.2
P0.13/2.6C: U$1.P$AD8 (P0.13)
P0.14/1.5D: C31.2, R8.1, SW_ENT.2
P0.19: U$1.P$AC15 (P0.19)
P0.20: U$1.P$AD16 (P0.20)
P0.21: U$1.P$AC17 (P0.21)
P0.22: U$1.P$AD18 (P0.22)
P0.23: U$1.P$AC19 (P0.23)
P0.24: U$1.P$AD20 (P0.24)
P0.25: U$1.P$AC21 (P0.25)
P0.26: U$1.P$G1 (P0.26)
P0.27: U$1.P$H2 (P0.27)
P0.30: U$1.P$B9 (P0.30/AIN6)
P0.31: U$1.P$A8 (P0.31/AIN7)
P1.01/1.6C: Q1.1 (G), R_PWR_EPD.1
P1.01/2.4B: U$1.P$Y23 (P1.01)
P1.02/2.8C: U$1.P$W24 (P1.02)
P1.03: U$1.P$V23 (P1.03)
P1.04: U$1.P$U24 (P1.04)
P1.05: U$1.P$T23 (P1.05)
P1.06: U$1.P$R24 (P1.06)
P1.07: U$1.P$P23 (P1.07)
P1.09: U$1.P$R1 (P1.09)
P1.10: U$1.P$A20 (P1.10)
P1.11: U$1.P$B19 (P1.11)
P1.12: U$1.P$B17 (P1.12)
P1.13: U$1.P$A16 (P1.13)
P1.14: U$1.P$B15 (P1.14)
P1.15: U$1.P$A14 (P1.15)
P.014/2.7C: U$1.P$AC9 (P0.14)
PMIC_INT: IC1.A1 (!INT), U$1.P$T2 (P0.11)
PREVGH: D5.1 (K), EPD_C9.2, J1.21
PREVGL: D2.2 (A), EPD_C11.2, J1.23
RESET: J1.3, J2.6, Q3.2 (S), R1_EP_DR.2, U$1.P$AC13 (P0.18/RESET)
SCK/1.5B: J1.13
SCK/2.2D: U$1.P$A12 (P0.02/AIN0)
SCL/1.4C: IC2.C1 (SCL), U3.7 (SCL)
SCL/2.4C: IC1.B1 (SCL), IC3.12 (SCX), R4.1, R17.2, U$1.P$M2 (P0.07)
SDA/1.4C: IC2.B2 (SDA), U3.8 (SDA)
SDA/2.4C: IC1.C1 (SDA), IC3.2 (SDX), R2.1, R18.2, U$1.P$L1 (P0.06)
SWDCLK: J2.4, U$1.P$AA24 (SWDCLK)
SWDIO: J2.2, U$1.P$AC24 (SWDIO)
SWO: U$1.P$AD22 (P1.00)
VBAT/1.2A: C27.2, U3.2 (CELL), U3.3 (VDD)
VBAT/2.5C: C37.2, IC1.C2 (BAT)
VBUS/1.5D: C42.2, C43.1, D3.5 (VBUS), J4.A4_B9 (VBUS), J4.A9_B4 (VBUS)
VBUS/2.6D: C21.1, C38.2, IC1.A2 (IN), U$1.P$AD2 (VBUS)
VREG: C39.2, IC1.B2 (SYS)

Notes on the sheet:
SWD
TP_SWO
TP_SWDCLK
TP_SWDIO
TP_RESET
TP_3.3V
TP_GND
IMU
TP_SCL
TP_SDA
TP_3V3
TP_VREG
DC/DC
LiPo Charger
E-paper Drive Circuit
TP_OP
TP_ON
Haptic Driver
E-Paper Display Connector
TP_VBAT
TP_BAT_GND
Fuel Gauge
Buttons
USB C Connector & ESD Protection

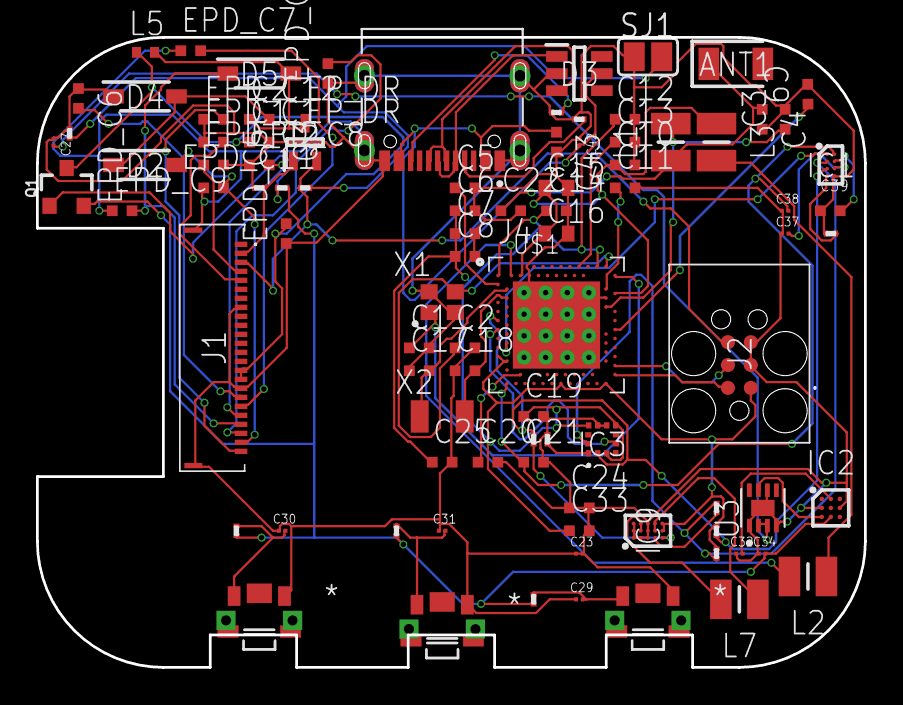
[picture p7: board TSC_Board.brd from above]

Board: 4 copper layers, 46.0 x 35.0 mm, 91 parts (0 on the bottom side), 61 nets.

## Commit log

2026-04-11 Adaugare fisier .sch
    [TSC_Schema.sch]
2026-04-18 Added .brd file
    [TSC_Board.brd]
2026-04-19 Added Print-out PDF

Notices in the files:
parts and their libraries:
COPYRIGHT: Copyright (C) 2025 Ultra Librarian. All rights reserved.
